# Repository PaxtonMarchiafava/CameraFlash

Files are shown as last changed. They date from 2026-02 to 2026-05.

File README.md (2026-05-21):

# CameraFlash

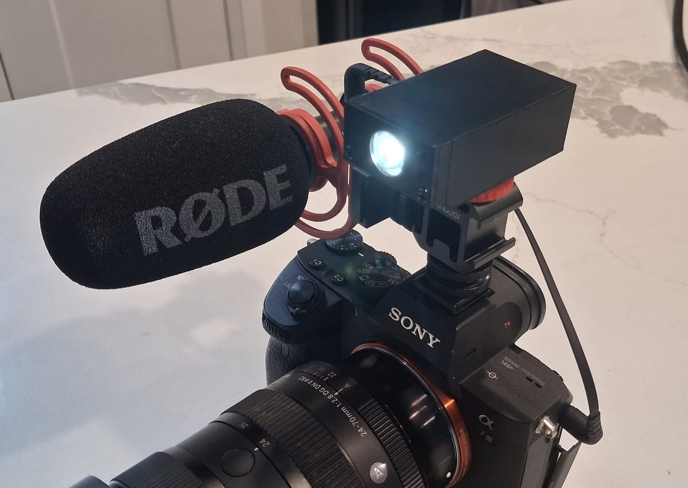
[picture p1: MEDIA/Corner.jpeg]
Corner View of the Prototype


A compact camera-mounted flashlight/torch built for a Sony a7III, designed to sit on a cold shoe adapter. Brightness is adjustable across 15 levels via two buttons, with deep sleep between presses for extremely low idle current (~15µA).

---

## Hardware

| Component | Part | Role |
|:---|:---|:---|
| Microcontroller | ATtiny202-SSNR | Main controller (2KB flash) |
| LED Driver | LM2759 | I2C-controlled torch/flash driver |
| High Power LED | MHP2016SWDT-Q05 | Torch/flash output |
| Battery Charger | BQ25170DSGR | Single-cell LiPo charger via USB-C |
| Status LED | KT-0603R | Charge status indicator |
| Power Good LED | NCD0603B5 | Charger power-good indicator |
| USB-C Port | TYPE-C-31-M-12 | Charging input |
| Buttons | TS-1187A-B-A-B (x2) | Brightness up / brightness down |

I2C pull-ups are 4.7kΩ. Battery protection IC was removed — the body diode forward voltage drop was causing problems. Bulk capacitance footprints are populated partially to fill empty PCB space.

Schematic found [here](ELECTRICAL/Schematic_CameraFlashlight.pdf)

---

## Software

Built with PlatformIO using the megatinycore Arduino framework, compiled with `-Os` for size.

**Button behavior:**
- **Button 1 (PA7):** Brightness up — increments through 14 torch levels, wraps back to off
- **Button 2 (PA3):** Brightness down — decrements through levels, wraps around to max

The MCU enters sleep mode between button presses and wakes on a level-triggered pin interrupt, keeping idle current minimal.

Brightness is written to the LM2759 over I2C. At level 0 the driver is shut down; levels 1–14 set the torch current register and enable torch mode.

---

## Power

| Source | Idle Current | Condition |
|:---|:---|:---|
| ATtiny202 | 5 µA | Standby sleep |
| LM2759 | 9.7 µA | Shutdown |
| BQ25170 | 0.35 µA | Unplugged |
| **Total** | **~15 µA** | LED off |

With a 4000 mAh battery, idle battery life is approximately

$$
\begin{align}
\frac{Battery Capacity}{Current Consumption} =& Hours \\
\frac{4000 mAh}{0.00001505 A}=& Hours\\
265780 Hours \approx& 30 years
\end{align}
$$

---

## Mechanical

3D printed enclosure, 5 parts. Attaches via cold shoe. Assembly notes:

- Leave clearance for the USB-C cable before tightening everything down. Misalignment makes it impossible to plug in. when putting it in a knife will be required to open up the USB-C hole slightly so the hole can be the exact same size as the port
- Screws thread directly into the print; don't overtorque
- Lens sits in the front of the enclosure

| Hardware | Qty |
|:---|:---:|
| M4 socket head bolt, 14mm | 1 |
| M3 countersunk bolt, 10mm | 3 |
| Lens | 1 |

---

## Known Issue: Lens Shadow

The back of the lens can cast a circular shadow in photos when the flash is mounted on the camera body. My lens is giant so it is probably a much larger issue for me than it is normally.

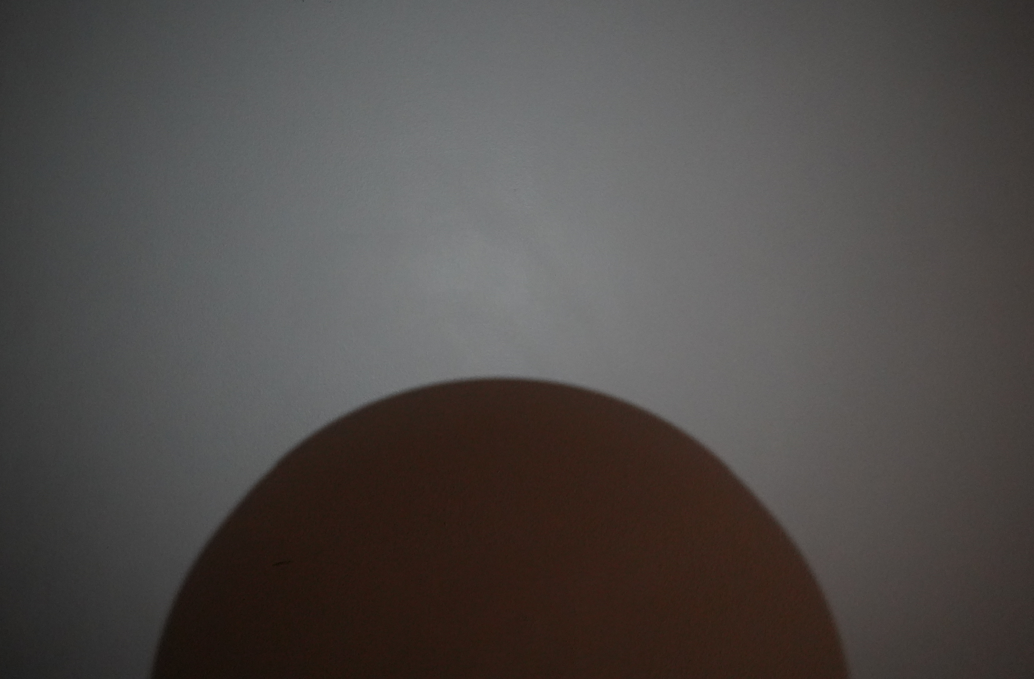
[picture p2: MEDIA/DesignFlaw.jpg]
Lens shadow on wall


**Workaround:** Mount the flash on a cold shoe 3-to-1 adapter above the camera body so the lens no longer blocks the light path.

## Battery Rattle Fix

The batteries have a small clearance gap between them and the case, causing them to rattle when the flash is moved. Folding up the plastic bag the batteries came in and wedging it between the two cells fills the gap perfectly. Problem solved + ReduceReuseRecycle

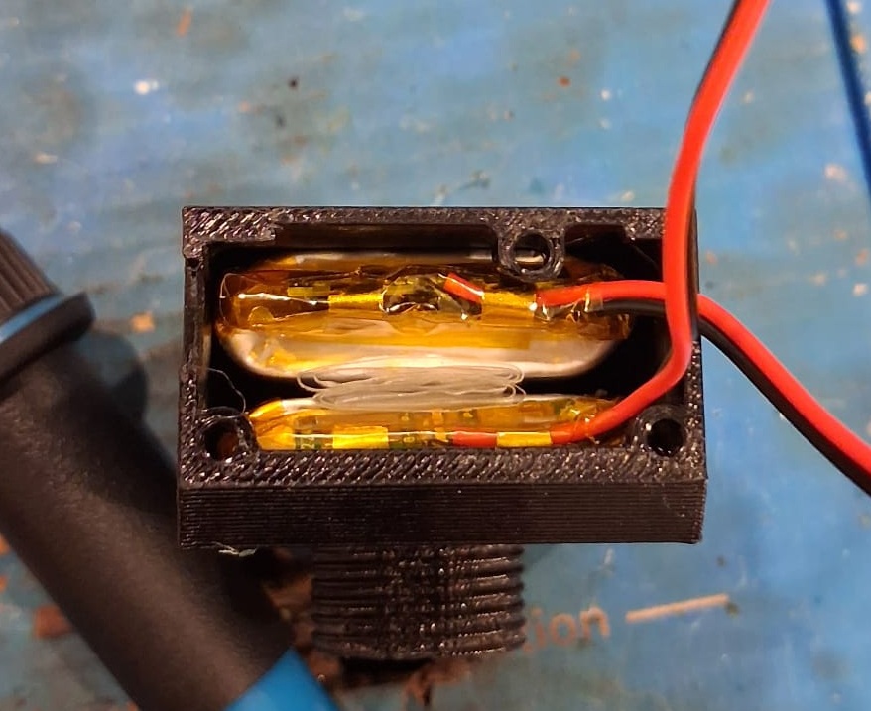
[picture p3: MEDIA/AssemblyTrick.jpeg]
Battery gap fix using packaging


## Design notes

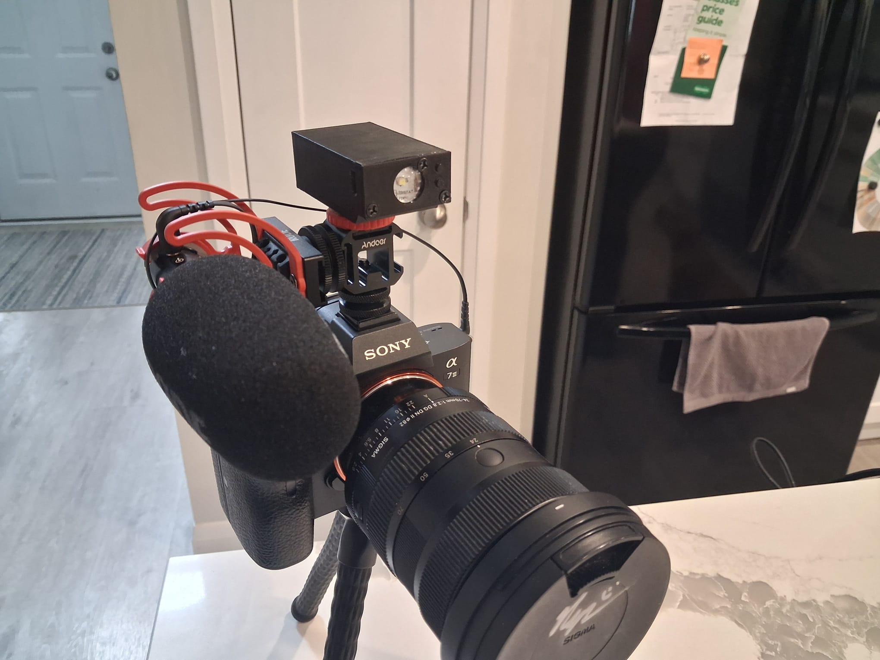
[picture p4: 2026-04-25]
MEDIA/OtherCorner.jpeg

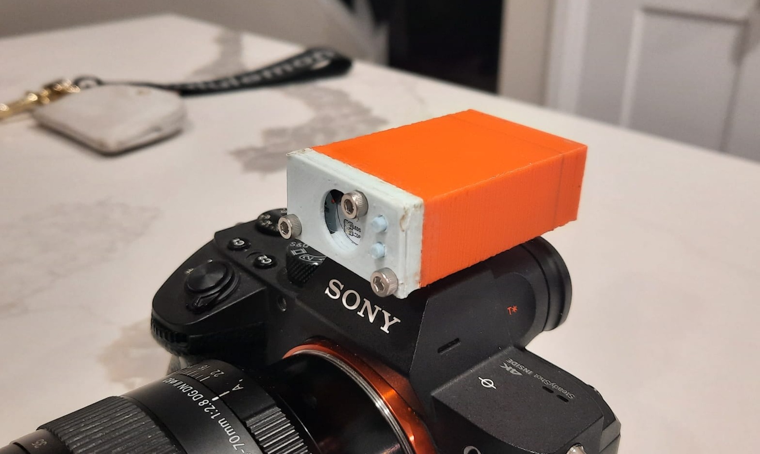
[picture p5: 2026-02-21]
MEDIA/PrototypeCorner.jpeg

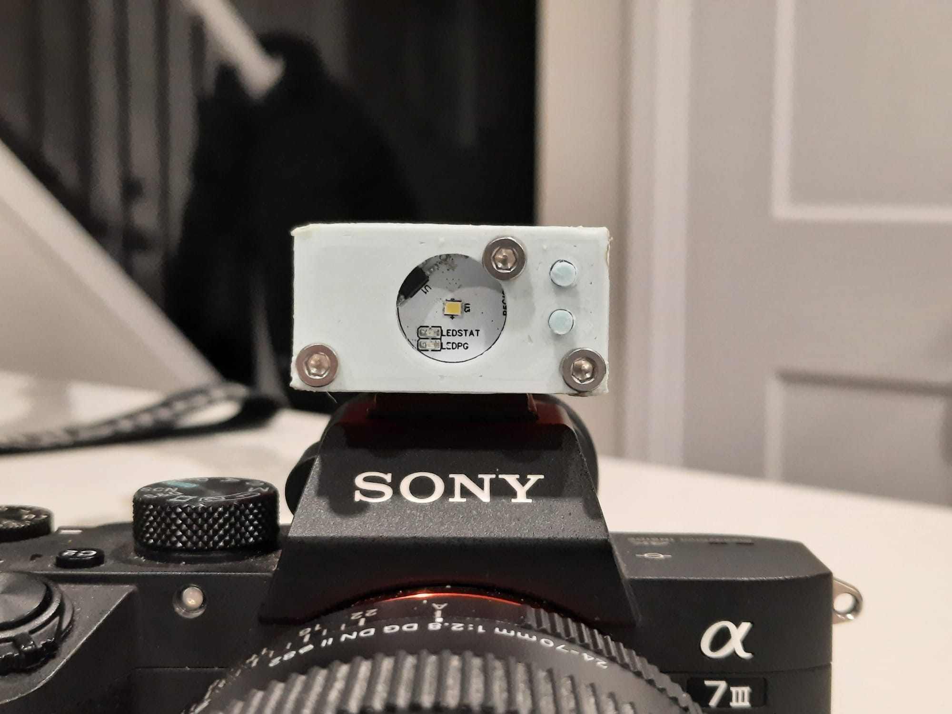
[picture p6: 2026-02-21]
MEDIA/PrototypeFront.jpeg

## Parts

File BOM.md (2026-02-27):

# Bill of Materials

## Mechanical

Most of the mechanical stuff is the 3d prints. no special printing needed. When assembling, make sure there is clearance to plug in the usbc cable. If stuff isn't aligned, you wont be able to plug it in. screws thread directly into print. be careful not to over torque and strip the hole of anything it would have that the screw could hold onto.

| item | count |
|:---:|:---:|
| 14mm M4 socket head bolt | 1 |
| 10mm M3 countersunk bolt | 3 |
| 3d prints | 5 files currently, one of each |
| lens | 1 |

## Electrical

bom that I used to order my parts ~~is~~```is going to be soon``` in the Electrical folder. I buy my parts from lcsc so an upload of the file there should work. The small items like the resistors are super cheap so I bought a few thousand because I will probably use them again.

| item | count | function |
|:---:|:---:|:---:|
| PCB | 1 |  |
| ATTINY202 / 402 | 1 | Micro controller |
| LM2759 | 1 | LED driver |
| DW01-A | 1 | battery protection |
| BQ25170DSGR | 1 | battery charger |
| 1k 0604 resistor | 7 |  |
| 4.7k 0604 resistor | 2 |  |
| 5.1k 0604 resistor | 2 |  |
| 39k 0604 resistor | 1 |  |
| 100nF 0604 capacitor | 4 |  |
| 1uF 0604 capacitor | 1 |  |
| 2.2uF 0604 capacitor | 3 |  |
| KT-0603R | 1 | status led |
| NCD0603B5 | 1 | PG led |
| TS-1187A-B-A-B | 1 | low profile button |
| MHP2016SWDT-Q05 | 1 | High power led that functions as the flash |
| TYPE-C-31-M-12 | 1 | usbc port |

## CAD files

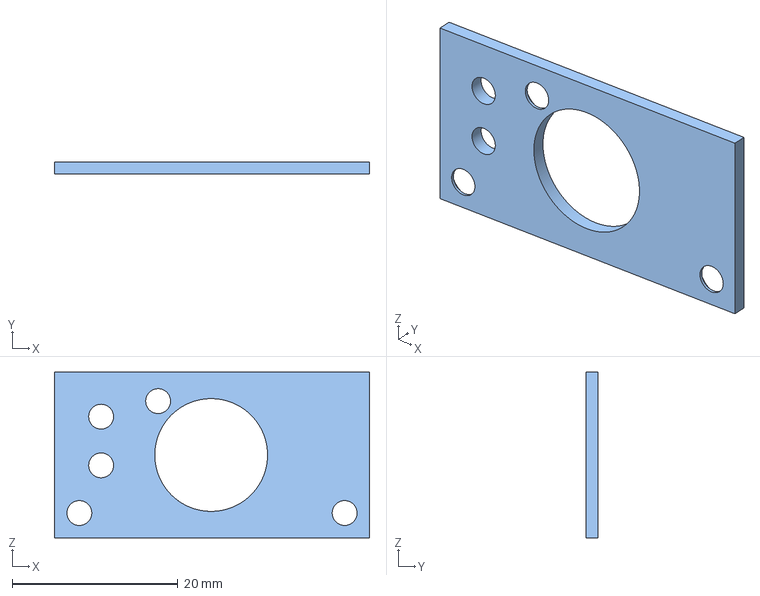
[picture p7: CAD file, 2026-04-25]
Mech/3mf/Face.3mf
38.0 x 1.50 x 20.0 mm

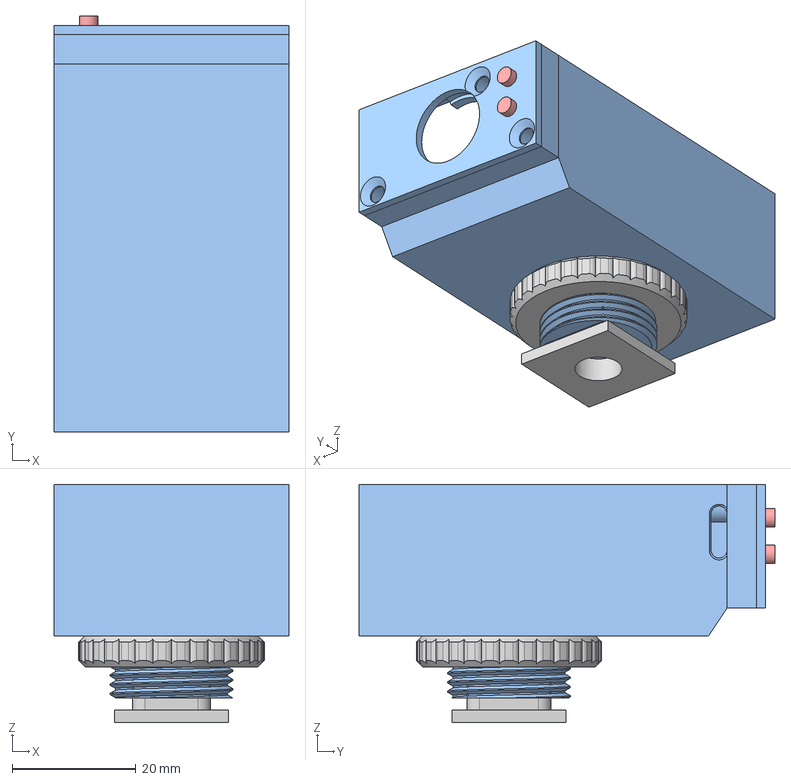
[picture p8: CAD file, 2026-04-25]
Mech/CameraFlash.step
38.0 x 67.2 x 38.5 mm

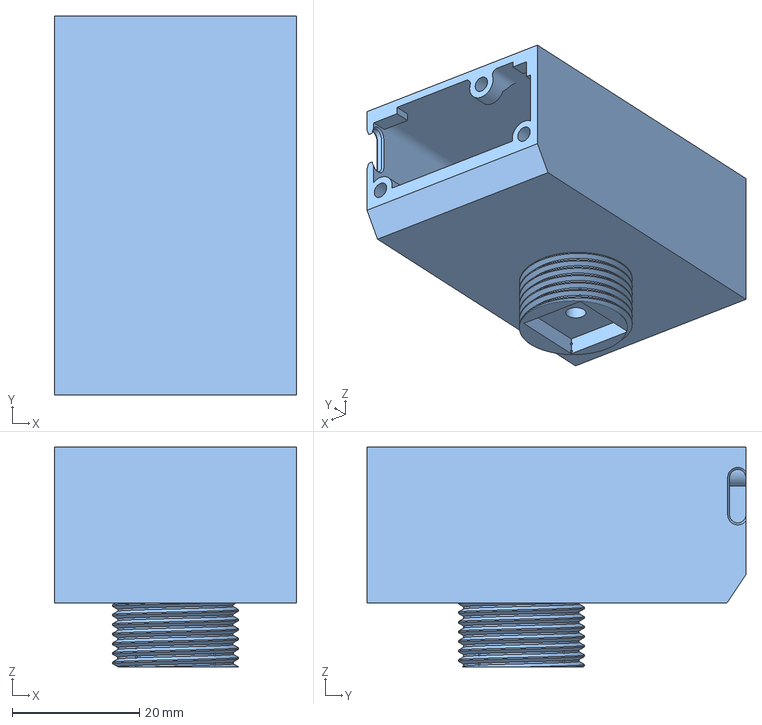
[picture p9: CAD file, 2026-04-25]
Mech/3mf/BacksideCase.3mf
38.0 x 59.5 x 34.5 mm

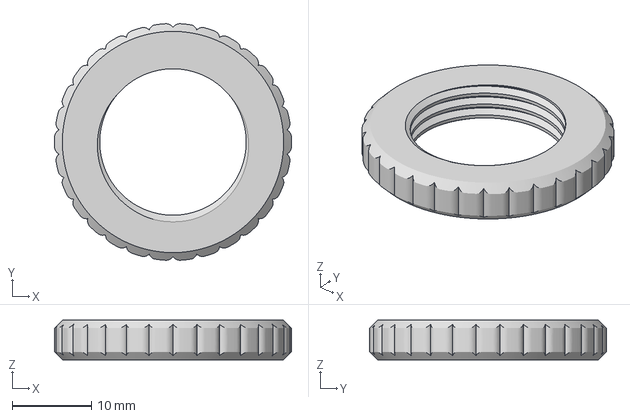
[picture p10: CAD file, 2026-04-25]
Mech/3mf/ColdShoeNut.3mf
30.0 x 29.9 x 5.00 mm

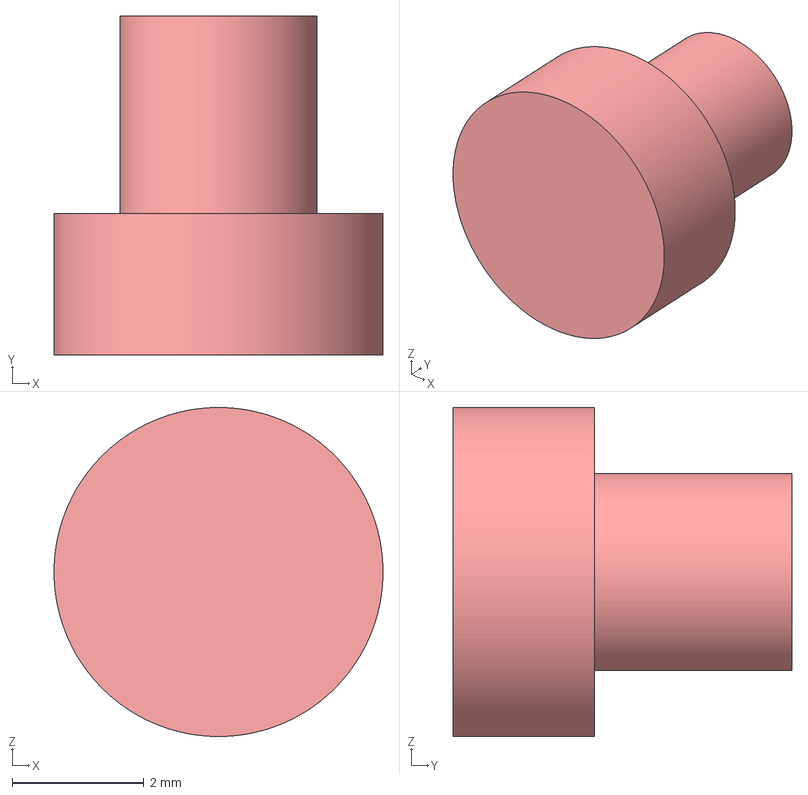
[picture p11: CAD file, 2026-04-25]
Mech/3mf/Button1.3mf
5.00 x 5.15 x 5.00 mm

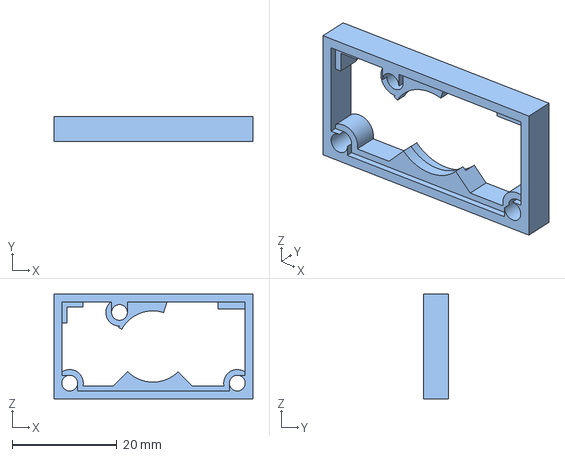
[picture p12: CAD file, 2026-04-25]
Mech/3mf/Mid.3mf
38.0 x 4.75 x 20.0 mm

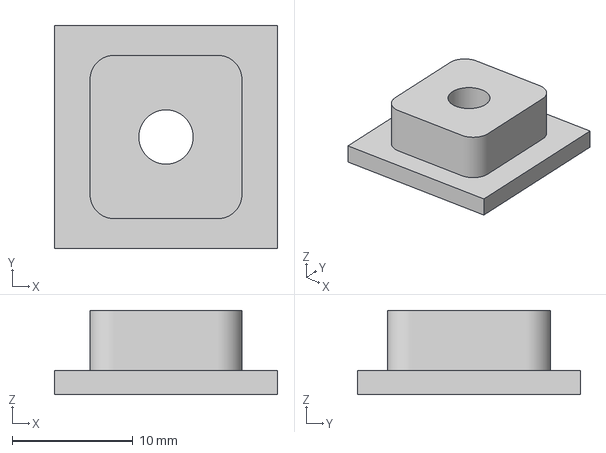
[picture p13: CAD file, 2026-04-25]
Mech/3mf/ColdShoe.3mf
18.5 x 18.5 x 7.00 mm

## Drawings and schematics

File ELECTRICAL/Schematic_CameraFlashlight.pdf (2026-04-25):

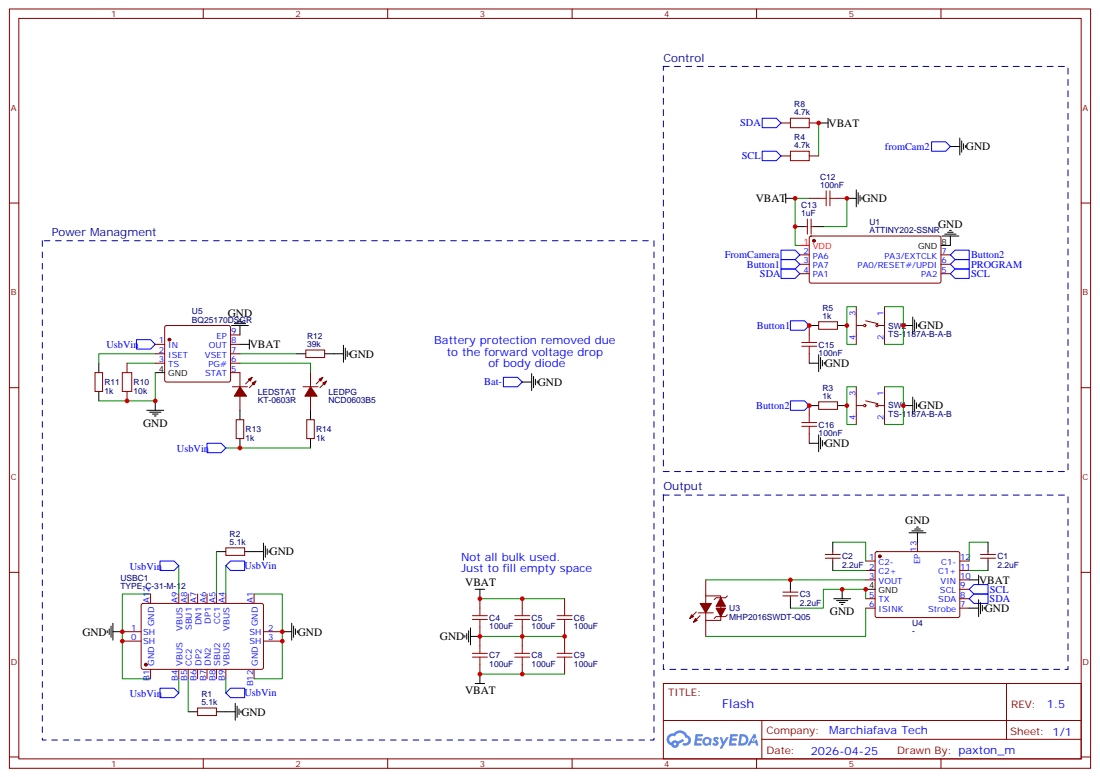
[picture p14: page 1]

Battery protection removed due
to the forward voltage drop

Not all bulk used.
Just to fill empty space

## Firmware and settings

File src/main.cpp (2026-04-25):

// using the compiler flag -Os

#include <Arduino.h>
#include <Wire.h> // i2c

#include <avr/sleep.h> // sleep
#include <avr/interrupt.h>
#include <avr/power.h>
#include <avr/wdt.h>
#include <avr/io.h>

// constants
#define maxBrightnessLevel 14 // max 16

#define brightnessUpFlag 1
#define brightnessDownFlag 2

// I2C address
#define LM2759 83

#define button1 1 // pa7
#define button2 4 // pa3

uint8_t torchBrightness = 0; // datasheet max 15, because wee add 0 as an option this var can be 16 as max
uint8_t FlashBrightness = 4; // datasheet max 15
volatile uint8_t flags = 0;

/*
┌──────┐┌──────┐┌──────┐┌──────┐┌──────┐┌──────┐
│  ┌┐  └┘  ┌┐  └┘  ┌┐  └┘  ┌┐  └┘  ┌┐  └┘  ┌┐  │
│  │└──────┘└──────┘└──────┘└──────┘└──────┘│  │
│  │          Everything Functions          │  │
│  │┌──────┐┌──────┐┌──────┐┌──────┐┌──────┐│  │
│  └┘  ┌┐  └┘  ┌┐  └┘  ┌┐  └┘  ┌┐  └┘  ┌┐  └┘  │
└──────┘└──────┘└──────┘└──────┘└──────┘└──────┘
*/

// Write i2c data
uint8_t writeRegister(uint8_t device, uint8_t reg, uint8_t value) {
  Wire.beginTransmission(device);
  Wire.write(reg);
  Wire.write(value);
  Wire.endTransmission();
  
  // if (Wire.endTransmission() > 0) {
  //   batteryDead = 1;
  // } else {
  //   batteryDead = 1;
  // }
}

void writeBrightness() {
  if (torchBrightness > 0) {
    writeRegister(LM2759, 0xA0, (torchBrightness - 1));
    writeRegister(LM2759, 0x10, 0x09); // torch mode
  } else {
    writeRegister(LM2759, 0x10, 0x08); // set to shutoff
  }
}

/*
┌──────┐┌──────┐┌──────┐┌──────┐┌──────┐┌──────┐
│  ┌┐  └┘  ┌┐  └┘  ┌┐  └┘  ┌┐  └┘  ┌┐  └┘  ┌┐  │
│  │└──────┘└──────┘└──────┘└──────┘└──────┘│  │
│  │             Setup Functions            │  │
│  │┌──────┐┌──────┐┌──────┐┌──────┐┌──────┐│  │
│  └┘  ┌┐  └┘  ┌┐  └┘  ┌┐  └┘  ┌┐  └┘  ┌┐  └┘  │
└──────┘└──────┘└──────┘└──────┘└──────┘└──────┘
*/

// button1 interrupt routine
void ButtonInterrupt () {
  // PORTA.INTFLAGS = (1 << Button1);
  if (digitalRead(button1)) {
    flags |= 1;
  }

  if (digitalRead(button2)) {
    flags |= 2;
  }
  
}

void disablePeripherals() {
  ADC0.CTRLA &= ~ADC_ENABLE_bm; // disable adc
  SPI0.CTRLA &= ~SPI_ENABLE_bm; // disable spi
  USART0.CTRLB &= ~USART_RXEN_bm; // disable usart rx?
  USART0.CTRLB &= ~USART_TXEN_bm; // disable usart tx?
  TCA0.SINGLE.CTRLA &= ~TCA_SINGLE_ENABLE_bm; // disable 16-bit Timer/Counter Type A
  TCB0.CTRLA &= ~TCB_ENABLE_bm; // disable 16-bit Timer/Counter Type B
  AC0.CTRLA &= ~AC_ENABLE_bm; // disable Analog Comparator
  // TWI0.MCTRLA &= ~TWI_ENABLE_bm; // disable twi
  
  // CCP = CCP_IOREG_gc;
  // CLKCTRL.MCLKCTRLA = CLKCTRL_CLKSEL_OSCULP32K_gc;
  
  // BOD.CTRLA &= BOD_SAMPFREQ_1KHZ_gc;
}

void gpioSetup () {

  pinMode(button1, INPUT_PULLUP);
  pinMode(button2, INPUT_PULLUP);

  PORTA.PIN3CTRL = PORT_PULLUPEN_bm | PORT_ISC_LEVEL_gc;
  PORTA.PIN7CTRL = PORT_PULLUPEN_bm | PORT_ISC_LEVEL_gc;

  // setup extra pin as a test bit
  PORTA_DIR = PIN6_bm;
  PORTA_OUTSET = PIN6_bm;
  delay(100);
  PORTA_OUTCLR = PIN6_bm;

  // set_sleep_mode(SLEEP_MODE_PWR_DOWN);
  // sei();
}

ISR(PORTA_PORT_vect) {
  PORTA.INTFLAGS = 0xFF; // reset interrupt flag
  if (!digitalRead(button1)) {
    flags = brightnessUpFlag;
  }else if (!digitalRead(button2)) {
    flags = brightnessDownFlag;
  }
}

void i2cSetup () {
  Wire.begin();
  
  writeRegister(LM2759, 0x10, 0x08); // shutdown led driver
  writeRegister(LM2759, 0xA0, 0); // set torch current
  writeRegister(LM2759, 0xB0, FlashBrightness); // set Flash current
  writeRegister(LM2759, 0xC0, 0x02); // set Flash duration

}

void setup() {
  gpioSetup();
  i2cSetup();
  // disablePeripherals();

  delay(500);
  writeRegister(LM2759, 0xA0, 1);
  writeRegister(LM2759, 0x10, 0x09); // torch mode  

  // change clock speeds need to test
  // _PROTECTED_WRITE(CLKCTRL.MCLKCTRLB, 0);   // 20 MHz
  // _PROTECTED_WRITE(CLKCTRL.MCLKCTRLB, CLKCTRL_PDIV_4X_gc | CLKCTRL_PEN_bm);  // 5 MHz

  // PORTA_OUTSET = PIN6_bm;
  // delay(100);
  // PORTA_OUTCLR = PIN6_bm;
}

/*
┌──────┐┌──────┐┌──────┐┌──────┐┌──────┐┌──────┐
│  ┌┐  └┘  ┌┐  └┘  ┌┐  └┘  ┌┐  └┘  ┌┐  └┘  ┌┐  │
│  │└──────┘└──────┘└──────┘└──────┘└──────┘│  │
│  │             Loop Functions             │  │
│  │┌──────┐┌──────┐┌──────┐┌──────┐┌──────┐│  │
│  └┘  ┌┐  └┘  ┌┐  └┘  ┌┐  └┘  ┌┐  └┘  ┌┐  └┘  │
└──────┘└──────┘└──────┘└──────┘└──────┘└──────┘
*/

// set sleep modes
void sleepDevice() {
  // SLEEP_MODE_IDLE, SLEEP_MODE_STANDBY, SLEEP_MODE_PWR_DOWN
  set_sleep_mode(SLEEP_MODE_PWR_DOWN);
  
  // sleep_enable();
  sei(); // enable interrupt
  sleep_mode();
  cli(); // disable interrupt

  // sleep_disable();
}

// Increases the torch mode brightness
void brightnessUp () {
  if (torchBrightness < maxBrightnessLevel) { // brightness below max
    torchBrightness++;

  } else if (torchBrightness >= maxBrightnessLevel) { // wrap back around from max brightness to off
    torchBrightness = 0;
  }
  writeBrightness();

  /* else if ((torchBrightness >= maxBrightnessLevel)) { // flash
    writeRegister(LM2759, 0xB0, FlashBrightness); // set Flash current
    writeRegister(LM2759, 0x10, 0x08 + 0x03); // Set to flash mode
    delay(10);
    writeRegister(LM2759, 0xA0, torchBrightness - 1);
    writeRegister(LM2759, 0x10, 0x08 + 0x01); // set to torch mode
  
  }*/

  while (!digitalRead(button1)) {}
}

// Decreases the torch mode brightness
void brightnessDown () {
  if (torchBrightness > 0) {
    torchBrightness--;

  } else if (torchBrightness <= 0) { // torch already at 0, wrap around to max brightness
    torchBrightness = maxBrightnessLevel;
  }
  writeBrightness();


  while (!digitalRead(button2)) {}
}

void loop() {

  if (flags == brightnessUpFlag) {
    flags = 0;
    brightnessUp();

  } else if (flags == brightnessDownFlag) {
    flags = 0;
    brightnessDown();
  }

  sleepDevice();

}

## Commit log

2026-01-31 Sleep Working?
    I don't have a power meter so I don't know if sleep actually works
2026-02-01 Add Debounce circuit on buttons, change battery charger IC
2026-02-15 Added some features, changed the battery charger ic
2026-02-21 Initial Prototype done
2026-02-25 Added Battery Protection and Mechanical Files
    [BacksideCase.3mf, Button1.3mf, CameraFlash.step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]
2026-02-25 Moved Electronics to a folder, added gerber file
2026-02-27 wrap around brightness
    When the brightness down button is pressed and its already off, the brightness goes to max. also vice versa
2026-04-25 Brightness wraps now
    broke the code a while back so this fixes it and brightness wraps around now. Need to take out some test code still
    [BacksideCase.3mf, Button1.3mf, CameraFlash.step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]
2026-04-25 cleaned code + modified schematic
    Removed battery protection ic because it was dropping system voltage too much
    [main.cpp]
2026-05-21 fix display of battery life estimation
